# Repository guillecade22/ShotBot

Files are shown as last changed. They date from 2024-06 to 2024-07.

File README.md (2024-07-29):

# Shotbot - Autonomous Shot-Serving Robot
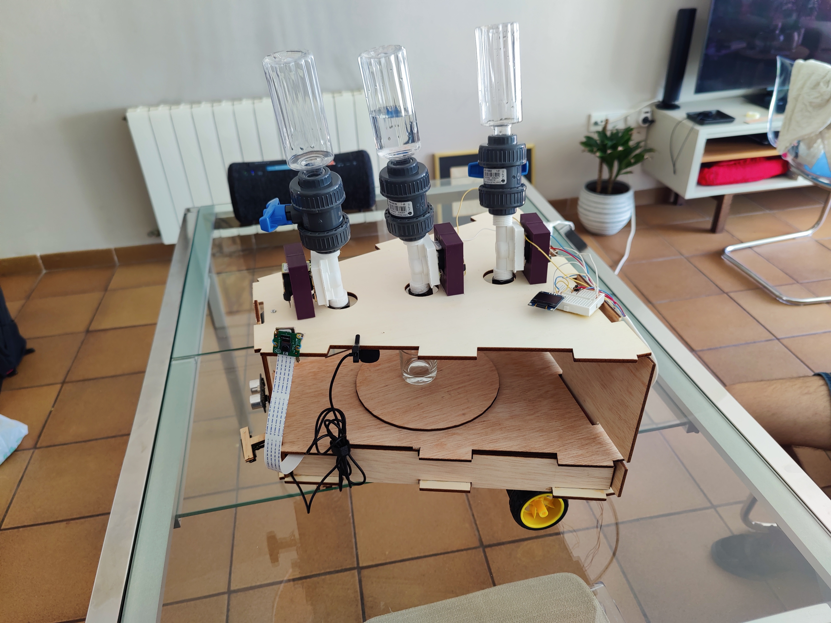
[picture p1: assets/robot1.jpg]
robot


# Table of Contents
   * [What is this?](#what-is-this)
   * [Requirements](#requirements)
   * [Installation](#installation)
   * [Hardware section](#hardware-section)
      * [3D Models](#3d-models)
      * [Components list](#components-list)
      * [Connections](#connections)
   * [Software section](#software-section)
      * [Movement](#movement)
      * [Audio](#audio)
      * [Serving shots](#serving-shots)
      * [Face detection](#face-detection)
   * [Video](#video)
   * [References](#references)
   * [Authors](#authors)

## What is this?
ShotBot is a small autonomous robot designed specifically for serving shots (drinks) in a bar setting. This project aims to create a new way for serving drinks by leveraging robotics technology. With its compact size and navigation system, ShotBot can maneuver through crowded bar spaces, delivering shots autonomously. Additionally, it is equipped with a camera for facial recognition and voice recognition capabilities, enhancing its interaction with customers.

## Requirements
For running this code, you need to install these languages and libraries:

- [Python 3.12.x](https://www.python.org/)
- [NumPy](https://numpy.org/)
- [Sklearn](https://scikit-learn.org/stable/)
- [Pillow](https://pillow.readthedocs.io/en/stable/)
- [opencv-python](https://pypi.org/project/opencv-python/)
- [luma.core](https://pypi.org/project/luma.core/)
- [PyAudio](https://pypi.org/project/PyAudio/)
- [Matplotlib](https://matplotlib.org/)
- [pygame](https://www.pygame.org/news)
- [wavefile](https://pypi.org/project/wavefile/)
- [RPi.GPIO](https://pypi.org/project/RPi.GPIO/)
- [pvleopard](https://pypi.org/project/pvleopard/)
- [pvporcupine](https://pypi.org/project/pvporcupine/)

## Installation
To set up ShotBot, follow these steps:
1. Clone the repository to your local machine.
2. Install the required libraries (check requirements).
3. Execute main Python script.

## Hardware section
The hardware library includes all the necessary components and designs for building Robowaiter's physical structure. It contains schematics, 3D designs, and hardware components to help you construct the robot.

### 3D Models
In the 3D library, you'll find printable designs for enclosures, mounts, and other physical structures required for Robowaiter. These designs are available to be 3D printed.
| 3D Piece | Image | 3D Piece | Image |
|---|---|---|---|
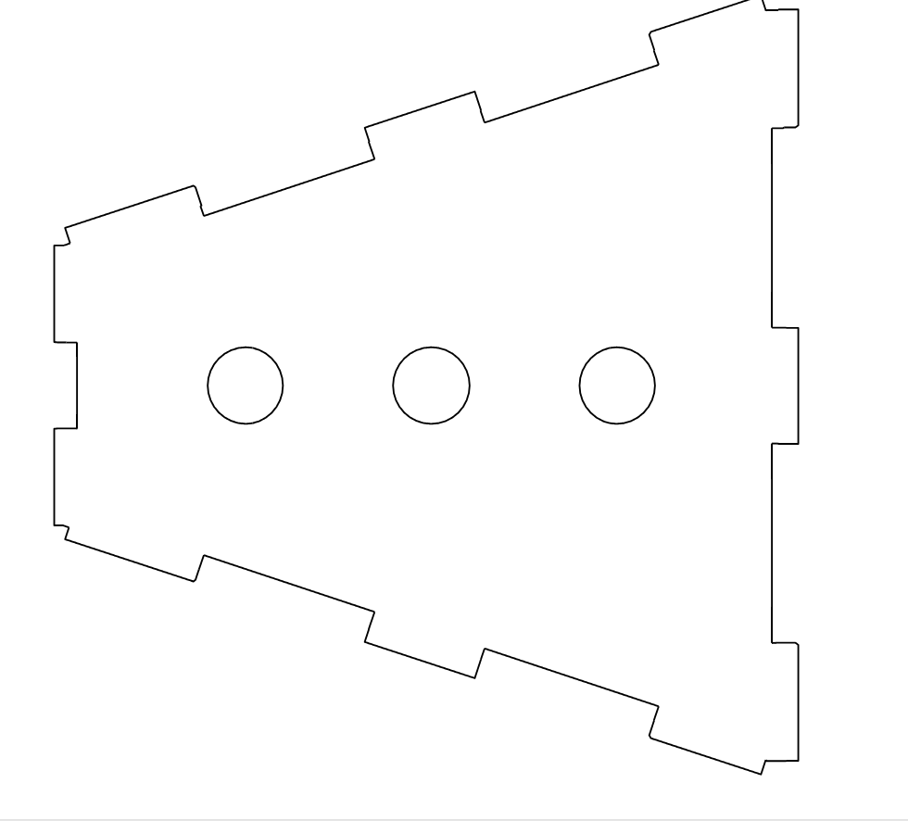
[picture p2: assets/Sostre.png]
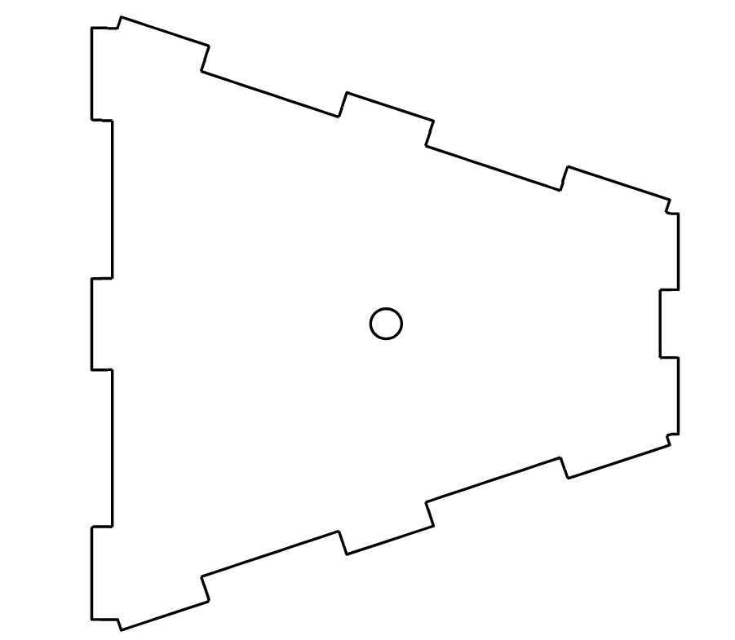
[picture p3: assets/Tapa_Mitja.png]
| Part superior |  | Base |  |
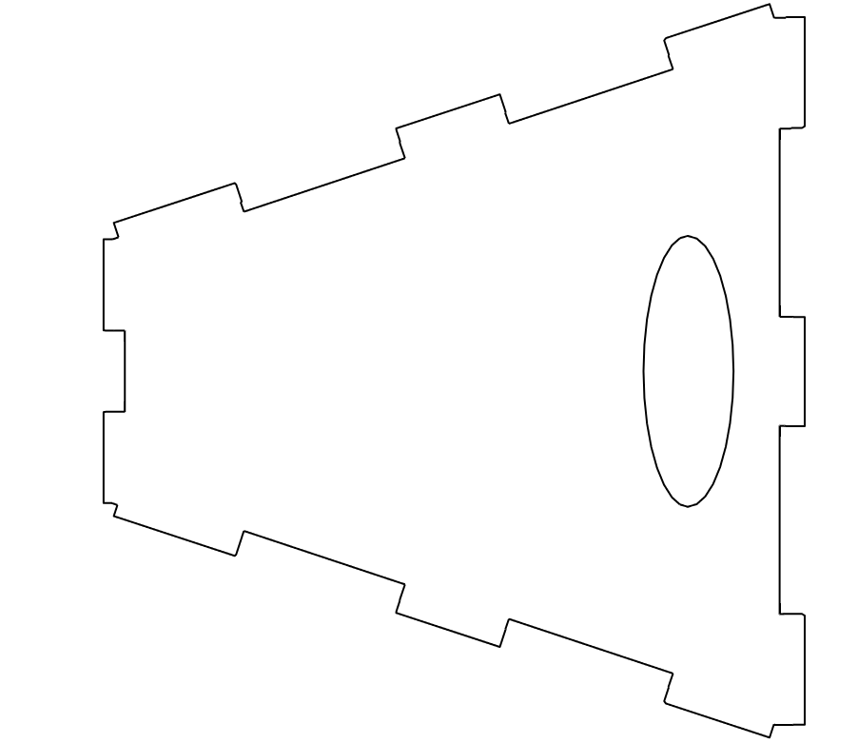
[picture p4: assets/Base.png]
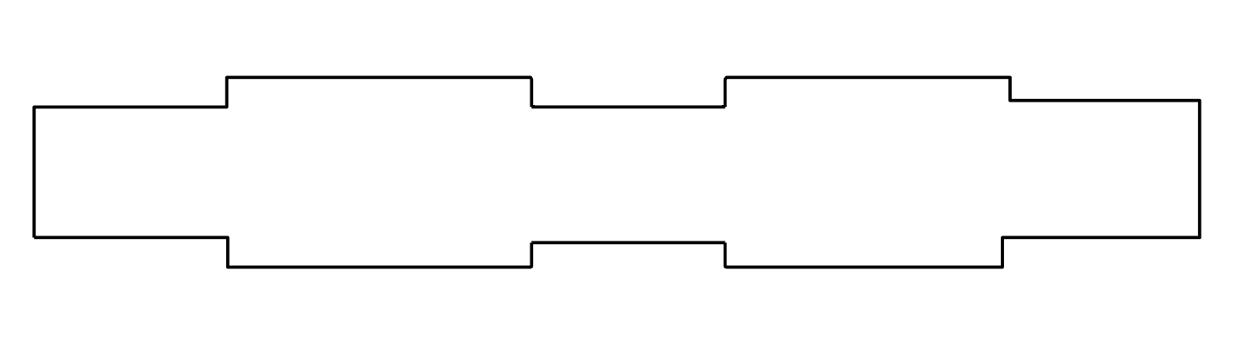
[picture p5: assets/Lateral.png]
| Part inferior |  | Part lateral x2  |  |
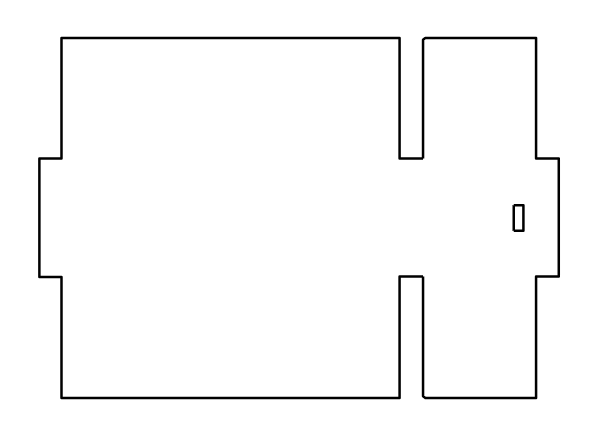
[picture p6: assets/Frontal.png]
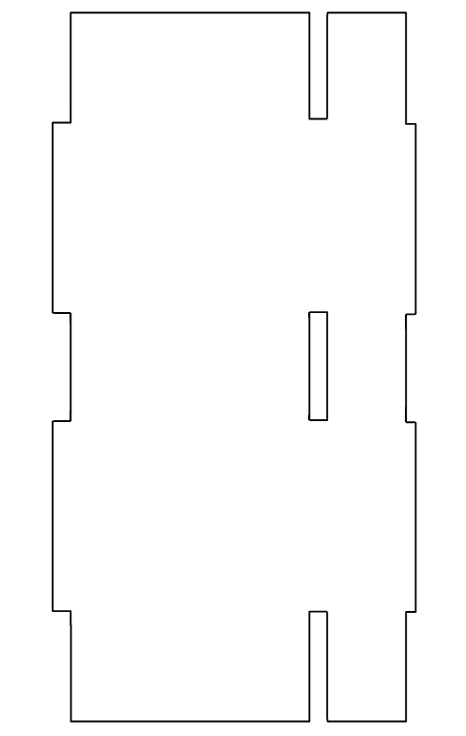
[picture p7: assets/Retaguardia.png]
| Front  |  | Back |  |
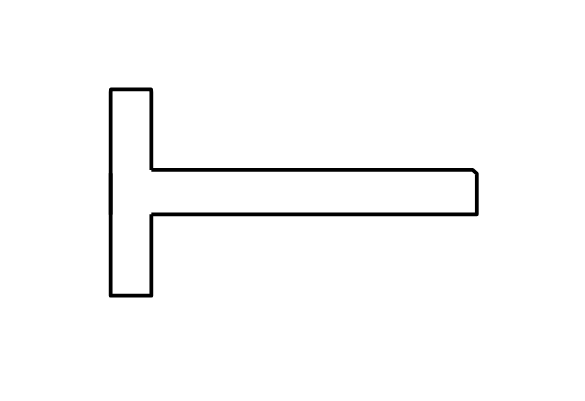
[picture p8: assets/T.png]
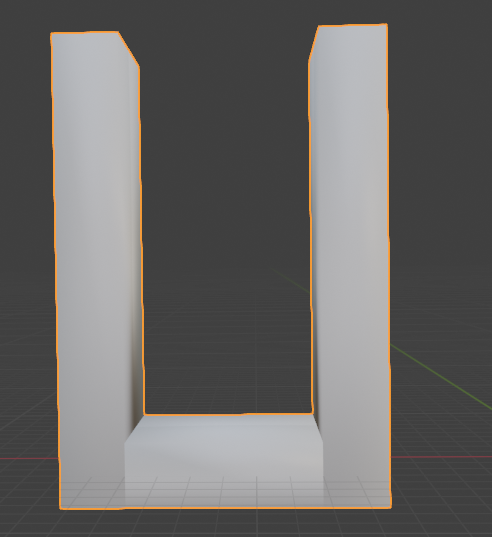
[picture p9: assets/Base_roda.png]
| Suport infraroig x2  |  | Suport roda motor x2 |  |
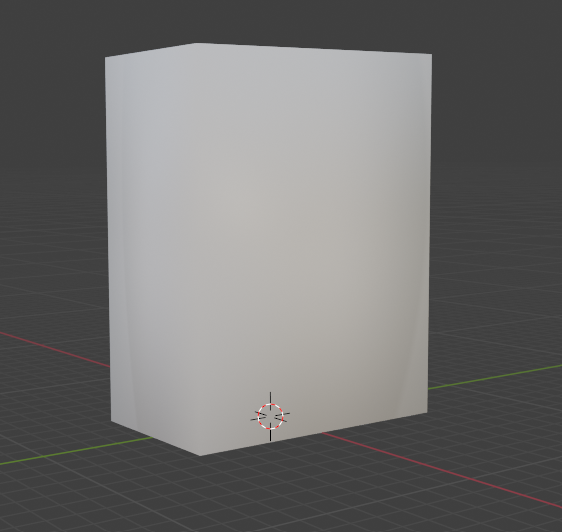
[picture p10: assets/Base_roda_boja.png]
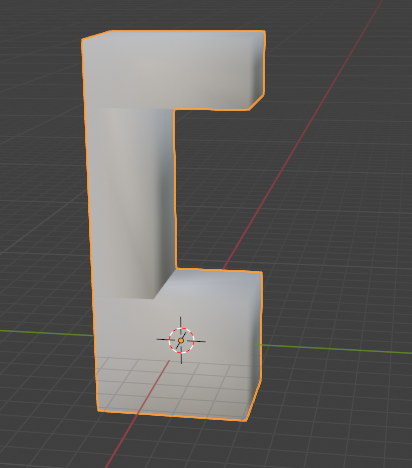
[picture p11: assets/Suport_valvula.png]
| Suport roda boja |  | Suport valvula x6 |  |
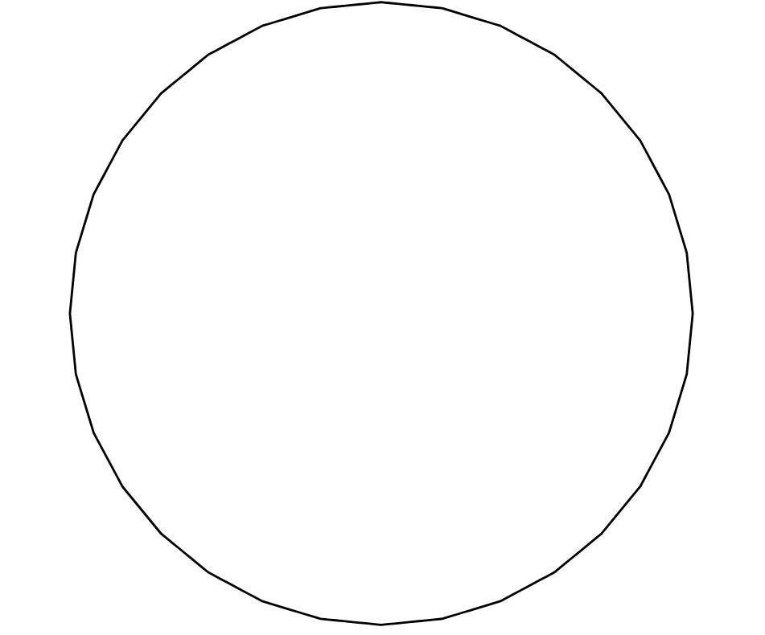
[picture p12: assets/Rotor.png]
|Plataforma||

### Components list
| Component | Image | Component | Image |
|---|---|---|---|
| [Raspberry Pi 3](https://tienda.bricogeek.com/placas-raspberry-pi/1089-raspberry-pi-3-b-plus.html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) |   | [Step-Up 3.3V to 12V](https://tienda.bricogeek.com/convertidores-de-voltaje/1004-conversor-step-upstep-down-33v1a-s7v8f3.html) |  |
| [Controller L298N](https://tienda.bricogeek.com/motores/285-controlador-de-motores-doble-puente-h-l298.html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) |  | [Camera](https://es.aliexpress.com/item/4001162865845.html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)  |  | 
| [PowerBank 10000mAh](https://www.amazon.es/Coolreall-10000mAh-Compacto-Pantalla-Compatible/dp/B0CQK1GVYD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) |  |[Ultrasound sensor x2](https://tienda.bricogeek.com/sensores-distancia/741-sensor-de-distancia-por-ultrasonidos-hc-sr04.html) | |
| [Solenoid Valve x3](https://tienda.bricogeek.com/otros-sensores/937-valvula-con-solenoide-12v.html) |  | [IR Sensor x2](https://www.amazon.es/AZDelivery-infrarrojos-kollissions-obst%C3%A1culos-Detecci%C3%B3n/dp/B07D924JHT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) |   | | [Batteries AA 1.5V x6](https://www.amazon.es/Verbatim-Pilas-Alcalino-Cil%C3%ADndrico-pieza/dp/B078TJF9WS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) |  |
| [Wheels + Motor x2](https://www.reichelt.com/es/es/motor-reductor-con-rueda-3-9-v-eje-de-3-5-mm-com-motor-rad-p219038.html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) |  | [Roda boja](https://fadisel.com/ca/roda-boja-o-roda-robotica/1054-roda-boja-acer-o-13-mm.html) |  |
[Microphone](https://www.amazon.es/Fyvadio-USB-Omnidireccional-Condensador-podcasting/dp/B0BZNJSMVM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)          |      | [Speakers](https://www.amazon.es/Hama-Sonic-Mobil-Negro-Altavoz/dp/B01EG0O104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)  |    |
|[Relay x3](https://tienda.bricogeek.com/interruptores/1352-modulo-rele-5v.html) |  | [Mini display LCD](https://tienda.bricogeek.com/pantallas-lcd/994-pantalla-lcd-color-160x80-096-con-microsd.html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) |  |

### Connections
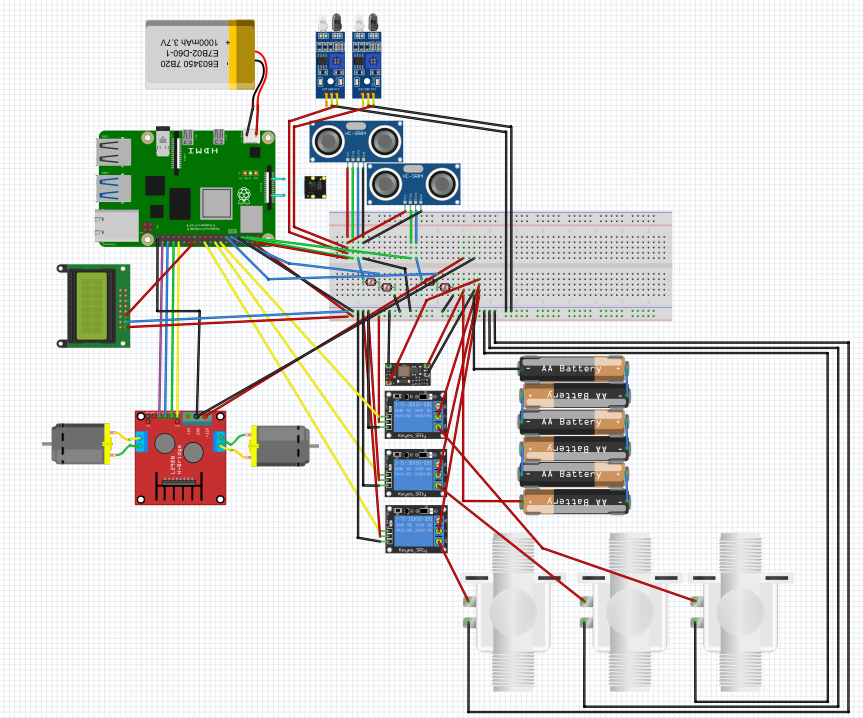
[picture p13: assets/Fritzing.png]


## Software section
The software library houses the codebase needed to operate Robowaiter effectively. It encompasses firmware for the robot's embedded systems, as well as any desktop applications or software components essential for seamless integration with the hardware.
There is an explanation below for each software module used by the robot. 

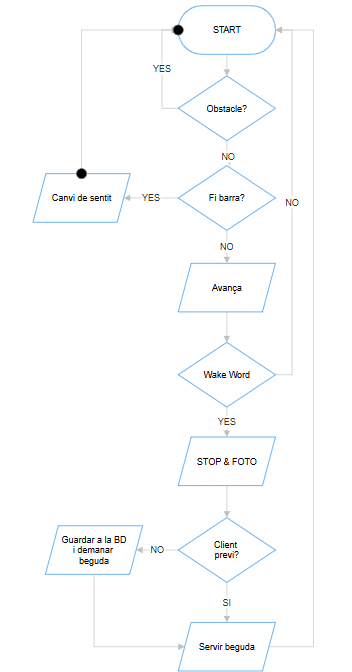
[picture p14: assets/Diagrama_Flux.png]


### Movement 
When the code is running, ShotBot starts moving forward until an obstacle is detected by the front ultrasound sensor or the infrared sensor is no longer detecting "ground".
If an obstacle is detected (within 25 centimeters), ShotBot stops and asks for the object to be removed using an audio. Once it is removed, ShotBot continues its way until the infrared sensor detects nothing. Then it starts moving backwards and repeats the cycle. The idea is to keep the robot moving all the time when there are no obstacles. There is a Wake Word defined (which can be modified) used to stop the robot and start asking for a drink. 

### Audio
Once the Wake Word is detected, ShotBot stops right where it is, and reproduces an audio, asking you to come closer to the camera. Then it take a photo and uses face detection to recognise you. If it is the first time you use the robot, it will save your photos in its database. If it is not the first time, it will automatically serve you the last drink you asked for.

### Serving shots
There are 3 different drinks. You can ask for any of these or a combination of all three. The robot will understand what you want and will tell you to put a glass under the valvule. Then the drink will start filling your glass and once it is done, you can just take it.

### Face detection
We are using a previous made algorithm for a different project we created before. It compares your photo with the database and gives a prediction within a threshold. In case you are not classified as an already existing user, it takes you 4 photos which will be saved in the database with a new ID. This way, ShotBot can remember your favorite drink and you will not need to ask for it again.

## Video
[https://youtu.be/NFXD42IQADw](https://youtu.be/NFXD42IQADw)

## References
- [Raspberry Pi 3 B+ Documentation and Tutorials](https://hetpro-store.com/TUTORIALES/raspberry-pi-3-b-plus-configuracion/)
- [Raspberry GPIO Samples](https://elinux.org/RPi_GPIO_Code_Samples)

## Authors
- Bonaventura Munill Díaz
- Guillem Cadevall Ferreres
- Marc Serrano Sanz
- Oscar Meca Moñino

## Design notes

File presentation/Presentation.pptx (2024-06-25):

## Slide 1

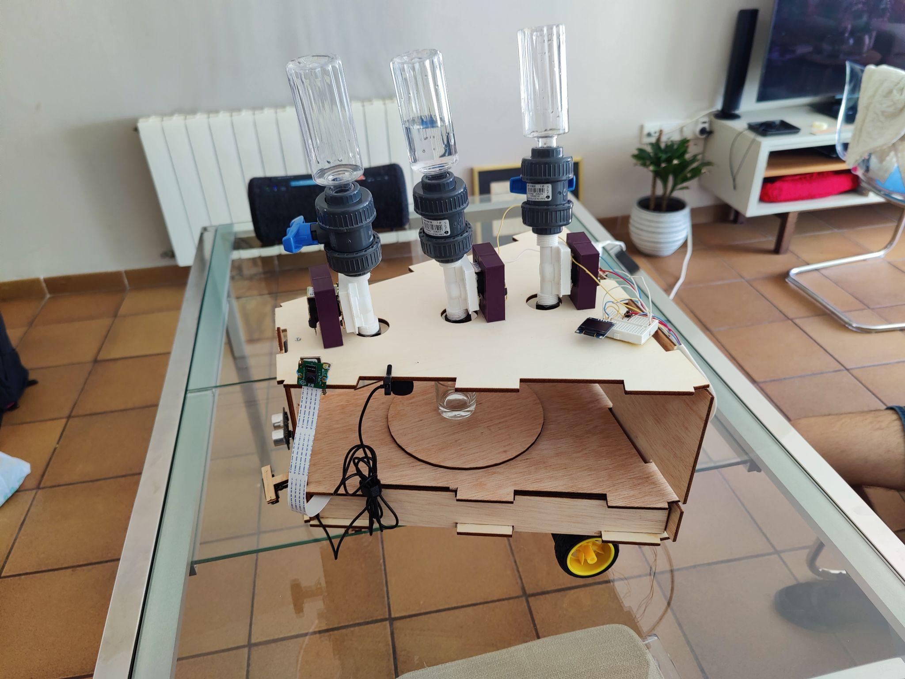
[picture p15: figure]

SHOTBOT

Bonaventura Munill Díaz - 1565808
Guillem Cadevall Ferreres - 1632005
Marc Serrano Sanz - 1632081
Oscar Meca Moñino - 1603973

ShotBot és un robot autònom i mòbil que serveix xupitos. Utilitza reconeixement facial per a reconèixer qui està demanant i speech-to-text per a entendre què vols.

ROBÒTICA, LLENGUATGE I PLANIFICACIÓ – ENGINYERIA INFORMÀTICA - UAB

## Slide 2

1. Arquitectura hardware i
software

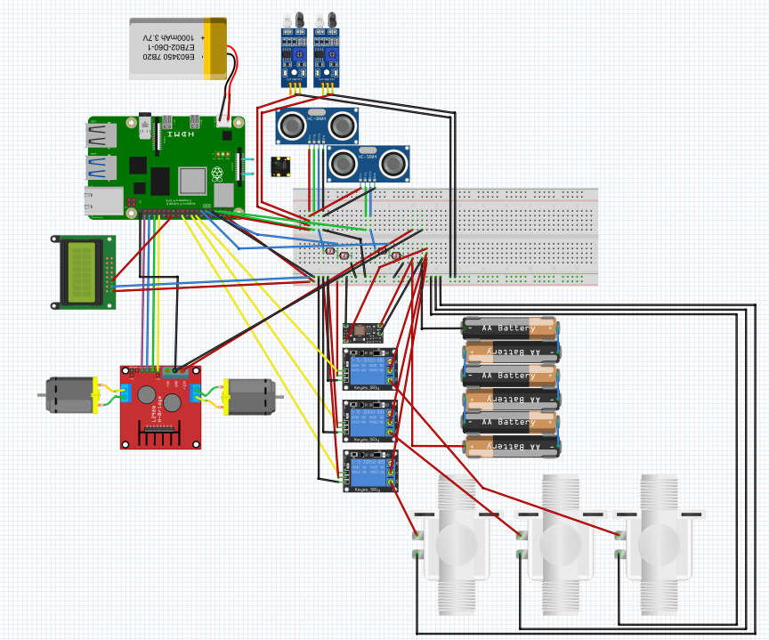
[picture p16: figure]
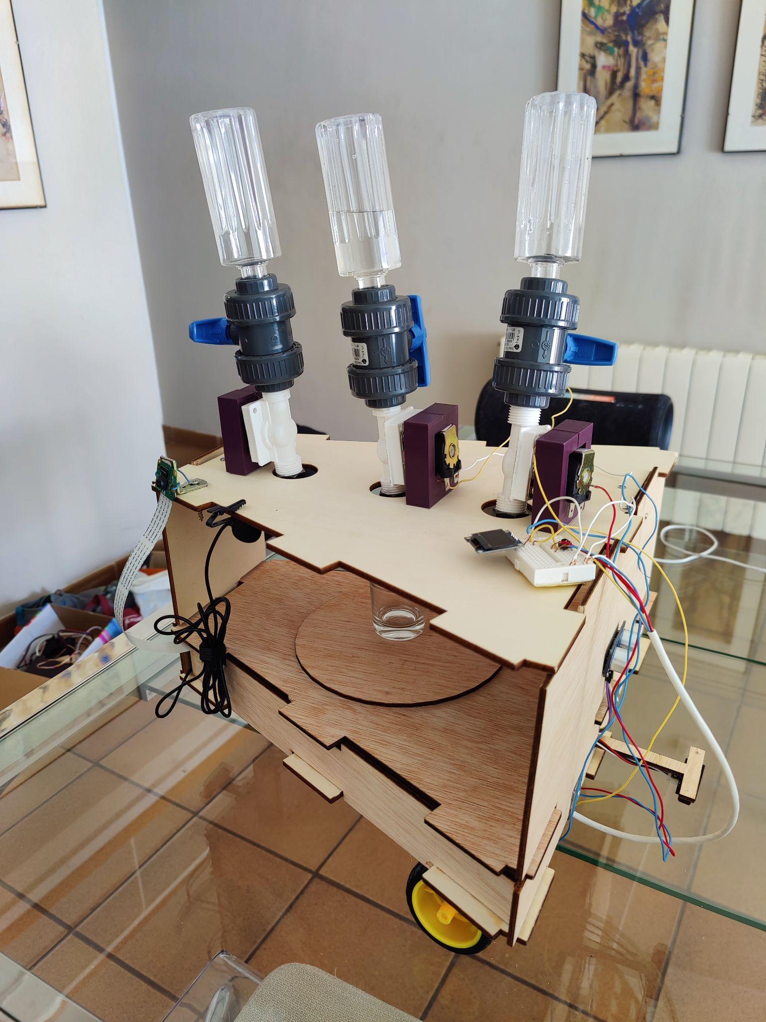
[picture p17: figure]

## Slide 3

2. Algorísmica

Moviment:
- Sensors
- WakeWord
Àudio
- Fitxers d’audio
- PicoVoice.ai
Reconeixement Facial
- Histograma Orientat de Gradients (HOG)
- Eigenfaces

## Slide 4

Estructura 3D, Vídeo i Git

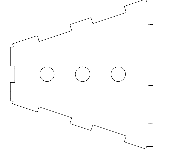
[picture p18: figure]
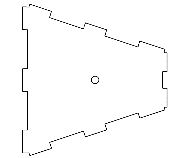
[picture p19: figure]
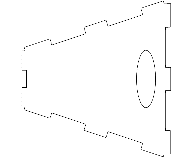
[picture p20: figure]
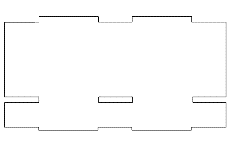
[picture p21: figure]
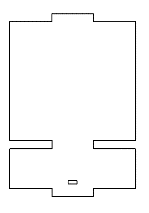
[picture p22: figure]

https://www.youtube.com/watch?v=NFXD42IQADw (youtube)

guillecade22/ShotBot (github.com) (https://github.com/guillecade22/ShotBot/)

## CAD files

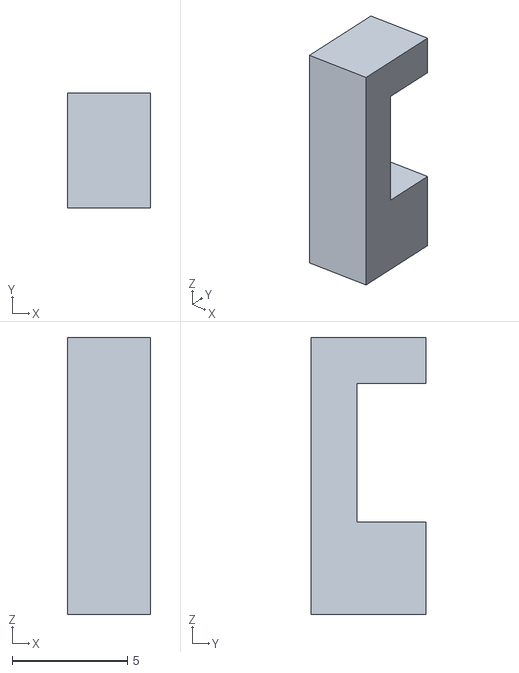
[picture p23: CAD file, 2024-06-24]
robot parts/suport valvula.stl
3.60 x 5.00 x 12.0

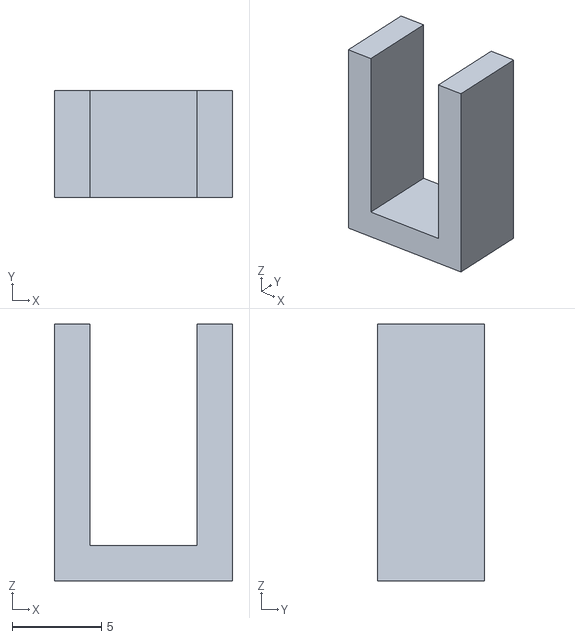
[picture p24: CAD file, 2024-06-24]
robot parts/base rodes.stl
10.0 x 6.00 x 14.4

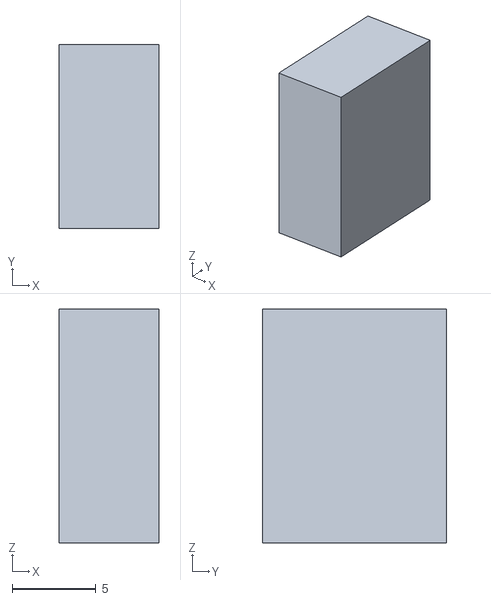
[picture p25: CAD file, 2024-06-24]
robot parts/base roda boja.stl
6.00 x 11.0 x 14.0

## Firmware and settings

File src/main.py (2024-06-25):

import RPi.GPIO as GPIO
import pygame
from time import sleep
import time
import pvporcupine
import pyaudio
import struct
import subprocess
import foto
import multiprocessing

def play_audio(file_path):
    pygame.mixer.init()
    pygame.mixer.music.load(file_path)
    pygame.mixer.music.play()
    while pygame.mixer.music.get_busy():
        sleep(0.1)

def get_distance(TRIG,ECHO):
    GPIO.output(TRIG, True)
    sleep(0.00001)
    GPIO.output(TRIG, False)

    while GPIO.input(ECHO) == 0:
        pulse_start = time.time()

    while GPIO.input(ECHO) == 1:
        pulse_end = time.time()

    pulse_duration = pulse_end - pulse_start
    distance = pulse_duration * 17150
    distance = round(distance, 2)
    return distance


#DISPLAY
display_process = multiprocessing.Process(target=subprocess.run, args=(["/home/pi/myenv/bin/python","/home/pi/Desktop/robot/display/logo.py"],), kwargs={"check": False})
display_process.start()

#Porcupine Setup
# Replace with your Picovoice access key
ACCESS_KEY = "-"

# Path to your custom wake word .ppn file
WAKE_WORD_PATH = "/home/pi/Desktop/robot/Quieto_es_raspberry-pi_v3_0_0.ppn"

# Path to the Spanish model file
MODEL_PATH = "/home/pi/Desktop/robot/porcupine_params_es.pv"

# Initialize Porcupine with the custom wake word and Spanish model file
porcupine = pvporcupine.create(
    access_key=ACCESS_KEY,
    keyword_paths=[WAKE_WORD_PATH],
    model_path=MODEL_PATH
)

# Initialize PyAudio
pa = pyaudio.PyAudio()

# Open audio stream
stream = pa.open(
    format=pyaudio.paInt16,
    channels=1,
    rate=porcupine.sample_rate,
    input=True,
    frames_per_buffer=porcupine.frame_length
)

#Ultrasonic sensors
"""
US_front = DistanceSensor(echo=23, trigger=24)
US_back = DistanceSensor(echo=25, trigger=8)
"""
# Pin Definitions
#US_Front
TF=24
EF=23
#US_Front
TB=8
EB=25
#Motor R
E1=12 #PWM
M1=5 #PDOut
#Motor L
E2=19 #PWM
M2=6 #PDOut
#IR sensors
IR_front = 4
IR_back = 26
#Relays
R1=17
R2=27
R3=22
#Start/Stop Button
#B=16

# Setup GPIO
GPIO.setmode(GPIO.BCM)  # Use BCM numbering
#Ultrasound
GPIO.setup(TF, GPIO.OUT)
GPIO.setup(TB, GPIO.OUT)
GPIO.setup(EF, GPIO.IN)
GPIO.setup(EB, GPIO.IN)
#Motor L
GPIO.setup(E1, GPIO.OUT)
GPIO.setup(M1, GPIO.OUT)
#Motor R
GPIO.setup(E2, GPIO.OUT)
GPIO.setup(M2, GPIO.OUT)
#IR sensors
GPIO.setup(IR_front, GPIO.IN)
GPIO.setup(IR_back, GPIO.IN)
#Relay
GPIO.setup(R1, GPIO.OUT)
GPIO.setup(R2, GPIO.OUT)
GPIO.setup(R3, GPIO.OUT)
#Start/Stop Button
#GPIO.setup(B, GPIO.IN)

motorR = GPIO.PWM(E1, 1000)  # 1 kHz frequency
motorL = GPIO.PWM(E2, 1000)  # 1 kHz frequency
motorR.start(0)
motorL.start(0)

direction = -1
GPIO.output(M1, GPIO.LOW) #Sentit  Agulles del rellotge
GPIO.output(M2, GPIO.LOW) #Sentit  Agulles del rellotge

speed=100

motorR.ChangeDutyCycle(speed)
motorL.ChangeDutyCycle(speed)

run=True


while run:

    #RUNNING FRONT
    if (direction == 1):
        
        if(GPIO.input(IR_front)!=1):#El sensor de davant torna 0, no hi ha terra
            motorR.ChangeDutyCycle(0)
            motorL.ChangeDutyCycle(0)
            sleep(0.5)
            GPIO.output(M1, GPIO.LOW) #Sentit Contrari Agulles del rellotge
            GPIO.output(M2, GPIO.LOW) #Sentit Contrari Agulles del rellotge
            motorR.ChangeDutyCycle(speed)
            motorL.ChangeDutyCycle(speed) 
            direction = -1
        
        if(get_distance(TF,EF)<25):
            print("Objecte davant")
            motorR.ChangeDutyCycle(0)
            motorL.ChangeDutyCycle(0)
            sleep(0.5)
            play_audio('/home/pi/Desktop/robot/audios/bloqueo_delantero.mp3')
            sleep(1)
            motorR.ChangeDutyCycle(speed)
            motorL.ChangeDutyCycle(speed) 
            
    #RUNNING BACK
    elif (direction == -1):
        
        if(GPIO.input(IR_back)!=1):#El sensor de darrera torna 0, no hi ha terra
            motorR.ChangeDutyCycle(0)
            motorL.ChangeDutyCycle(0)
            sleep(0.5)
            GPIO.output(M1, GPIO.HIGH) #Sentit Contrari Agulles del rellotge
            GPIO.output(M2, GPIO.HIGH) #Sentit Contrari Agulles del rellotge
            motorR.ChangeDutyCycle(speed)
            motorL.ChangeDutyCycle(speed)
            direction = 1
        if(get_distance(TB,EB)<25):
            print("Objecte davant")
            motorR.ChangeDutyCycle(0)
            motorL.ChangeDutyCycle(0)
            sleep(0.5)
            play_audio('/home/pi/Desktop/robot/audios/bloqueo_trasero.mp3')
            sleep(1)
            motorR.ChangeDutyCycle(speed)
            motorL.ChangeDutyCycle(speed) 

    #AUDIO & FACE RECOGNITION
    pcm = stream.read(porcupine.frame_length)
    pcm = struct.unpack_from("h" * porcupine.frame_length, pcm)
    keyword_index = porcupine.process(pcm)
    if keyword_index >= 0:
        motorR.ChangeDutyCycle(0)
        motorL.ChangeDutyCycle(0)
        print("Wake word detected!")
        sleep(1)
        foto.play_audio("/home/pi/Desktop/robot/audios/camara1.mp3")
        sleep(1)
        valvula = foto.identify()
        if(valvula=='1'):
            print(1)
            GPIO.output(R2,1)
            sleep(30)
            GPIO.output(R2,0)
        elif(valvula=='2'):
            print(2)
            GPIO.output(R1,1)
            sleep(30)
            GPIO.output(R1,0)
        elif(valvula=='3'):
            print(3)
            GPIO.output(R3,1)
            sleep(30)
            GPIO.output(R3,0)
        elif(valvula=='mezcla'):
            print('mezcla')
            GPIO.output(R1,1)
            GPIO.output(R2,1)
            GPIO.output(R3,1)
            sleep(30)
            GPIO.output(R1,0)
            GPIO.output(R2,0)
            GPIO.output(R3,0)
    

    
GPIO.cleanup()
stream.stop_stream()
stream.close()
pa.terminate()
porcupine.delete()

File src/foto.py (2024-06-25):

import numpy as np
import cv2
import pyaudio
from sklearn.decomposition import PCA
import matplotlib.pyplot as plt
from skimage.feature import hog
from time import sleep
import os
import subprocess
import pygame
import warnings
import random
import pvleopard as pv
import wave
warnings.filterwarnings("ignore")

def picture(save_path):
    # Command to capture an image using libcamera-still
    command = ["libcamera-still", "-o", save_path]

    try:
        # Execute the command
        subprocess.run(command, check=True)
        print(f"Image captured and saved to {save_path}")
    except subprocess.CalledProcessError as e:
        print(f"Error capturing image: {e}")

def play_audio(file_path):
    pygame.mixer.init()
    pygame.mixer.music.load(file_path)
    pygame.mixer.music.play()
    while pygame.mixer.music.get_busy():
        sleep(0.1)

def record_audio(file_path, duration=5, chunk_size=1024, sample_format=pyaudio.paInt16, channels=1, rate=44100):
    """Record audio from the microphone and save it to a WAV file."""
    
    # Initialize PyAudio
    audio = pyaudio.PyAudio()
    
    # Open audio stream
    stream = audio.open(format=sample_format,
                        channels=channels,
                        rate=rate,
                        frames_per_buffer=chunk_size,
                        input=True)
    
    print("Recording...")
    
    frames = []
    
    # Record audio in chunks
    for _ in range(int(rate / chunk_size * duration)):
        data = stream.read(chunk_size)
        frames.append(data)
    
    # Stop and close the stream
    stream.stop_stream()
    stream.close()
    
    # Terminate PyAudio
    audio.terminate()
    
    print("Finished recording.")
    
    # Save the recorded audio to a WAV file
    with wave.open(file_path, 'wb') as wf:
        wf.setnchannels(channels)
        wf.setsampwidth(audio.get_sample_size(sample_format))
        wf.setframerate(rate)
        wf.writeframes(b''.join(frames))

# Replace these paths with the actual paths on your system
ACCESS_KEY = '-'
MODEL_PATH_SPEECH = "/home/pi/Desktop/robot/robot-leopard.pv"

def recognize_speech():
    # Initialize Leopard
    leopard = pv.create(
        access_key=ACCESS_KEY,
        model_path=MODEL_PATH_SPEECH
    )

    file_path = "/home/pi/Desktop/robot/audios/recorded_audio.wav"
    record_audio(file_path, duration=3)
    
    transcript, words = leopard.process_file(file_path)
    leopard.delete()

    return transcript

def get_target(num):
    path = os.path.join("/home/pi/Desktop/robot/targets", num)
    print(path)
    with open(path + '/target.txt', 'r') as file:
        contenido = file.read()
    return contenido

def load_dataset(dataset_path):
    dataset = []
    num_folders = sorted(os.listdir(dataset_path), key=lambda x: int(x))
    
    for num_folder in num_folders:
        num_folder_path = os.path.join(dataset_path, num_folder)
        for img_name in os.listdir(num_folder_path):
            img_path = os.path.join(num_folder_path, img_name)
            img = cv2.imread(img_path)
            flipped = cv2.flip(img,1)
            flipped = np.array(flipped)
            flipped = cv2.cvtColor(flipped, cv2.COLOR_RGB2GRAY)
            img = cv2.cvtColor(img, cv2.COLOR_RGB2GRAY)
            
            random_value = random.uniform(1.2, 1.5)
            increase = np.ones((64, 64)) * random_value
            random_value = random.uniform(0.5, 0.8)
            decrease = np.ones((64, 64)) * 0.65
            
            img = img/255.0
            dataset.append((img, num_folder))
           
            flipped = flipped/255.0
            dataset.append((flipped, num_folder))
            
            bright_img = np.clip(img * increase, 0, 1)
            dataset.append((bright_img, num_folder))
            
            bright_flipped = np.clip(flipped * increase, 0, 1)
            dataset.append((bright_flipped, num_folder))
            
            bright_img2 = np.clip(img * decrease, 0, 1)
            dataset.append((bright_img2, num_folder))
            
            bright_flipped2 = np.clip(flipped * decrease, 0, 1)
            dataset.append((bright_flipped2, num_folder))
            
            random_value = random.uniform(0.02, 0.033)
            noise_img1 = img + np.random.normal(0, random_value, img.shape)
            noise_img1 = np.clip(noise_img1, 0, 1)
            dataset.append((noise_img1, num_folder))

            noise_img2 = flipped + np.random.normal(0, random_value, flipped.shape)
            noise_img2 = np.clip(noise_img2, 0, 1)
            dataset.append((noise_img2, num_folder))
            
            blur_img1 = cv2.GaussianBlur(img, (5, 5), 0)
            dataset.append((blur_img1, num_folder))
            blur_img2 = cv2.GaussianBlur(flipped, (5, 5), 0)
            dataset.append((blur_img2, num_folder))
           
    return dataset

def get_next_image_name(folder_path):
    # Find the highest numbered image file in the dataset folder
    existing_images = [f for f in os.listdir(folder_path) if f.startswith("img") and f.endswith(".png")]
    if not existing_images:
        return "img0.png"  # If no images found, start with img0.jpg
    else:
        highest_number = max([int(img.split("img")[1].split(".png")[0]) for img in existing_images])
        next_number = highest_number + 1
        return "img{}.png".format(next_number)

def capture_img(folder_number,save=True):
    
    dataset_folder = "/home/pi/Desktop/robot/dataset"
    
    picture("/home/pi/Desktop/robot/test.jpg")
    image = cv2.imread("/home/pi/Desktop/robot/test.jpg")

    grayscale_frame = cv2.cvtColor(image, cv2.COLOR_BGR2GRAY)
    
    face_cascade = cv2.CascadeClassifier(cv2.data.haarcascades + 'haarcascade_frontalface_default.xml')
    faces = face_cascade.detectMultiScale(grayscale_frame, scaleFactor=1.1, minNeighbors=5)
    if len(faces) > 0:
        (x, y, w, h) = faces[0]  # Assuming only one face is detected, you can modify this if needed
        face_image = grayscale_frame[y:y+h, x:x+w]
        grayscale_frame = cv2.resize(face_image, (64, 64))
        
        if save:
            folder_path = os.path.join(dataset_folder, str(folder_number))
            # Check if the folder exists, if not, create it
            if not os.path.exists(folder_path):
                os.makedirs(folder_path)
            # Save the grayscale image in the dataset folder
            next_img_name = get_next_image_name(folder_path)  # You need to define get_next_image_name() function
            img_path = os.path.join(folder_path, next_img_name)
            cv2.imwrite(img_path, grayscale_frame)
            
        # Release the webcam
        
        print("Image captured, resized to 64x64 pixels, converted to grayscale, and normalized")
        
        return grayscale_frame
    else:
        print("No face detected")
        return None
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
